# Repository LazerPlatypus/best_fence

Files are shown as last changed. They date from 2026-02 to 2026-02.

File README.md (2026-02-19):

# best_fence

3D-printable accessories for the Best Fence saw system.

## Overview

best_fence is an OpenSCAD design project that creates 3D-printable parts for working with the Best Fence woodworking measurement system.

**Features:**
- 3D-printable toe clamp system for securing the Best Fence to your workstation
- Modular mount design supporting 1–10 channels with configurable spacing
- Connectors for joining fence sections (butt connector) and mounting to saw horses

## Requirements

- **OpenSCAD** 2026.02.10 or newer
- **Python 3** (for documentation generation, optional)
- **openscad-docsgen** (installed via `make setup`)

## Quick Start

### 1. Preview
Open any file in `parts/` or `assemblies/` in OpenSCAD and press F5 to preview.

### 2. Build
```bash
make          # Build all STL files
```

### 3. Customize
Edit parameters in `config.scad` to adjust dimensions and settings.

## Building

```bash
# Build all parts
make

# Build specific part
make parts/butt_connector.scad build/stl/butt_connector.stl
make parts/saw_horse_connector.scad build/stl/saw_horse_connector.stl
make parts/toe_clamp_body.scad build/stl/toe_clamp_body.stl
make parts/toe_clamp_insert.scad build/stl/toe_clamp_insert.stl

# Generate documentation
make docs

# Render images
make images

# Clean build artifacts
make clean
```

## File Organization

- **[parts/](parts/)** - Printable 3D part source files
- **[assemblies/](assemblies/)** - Pre-configured assembly files for preview and export
- **[tools/](tools/)** - Reusable mount and attachment modules
- **[hardware/](hardware/)** - Hardware reference models (bolt, screw)
- **[scripts/](scripts/)** - Build automation scripts
- **[build/](build/)** - Generated STL files and images (run `make` to create)
- **[docs/](docs/)** - Documentation (hand-written + generated)
- **[config.scad](config.scad)** - Project-wide configuration

## Customization

All project settings can be adjusted in `config.scad`:
- Best Fence dimensions and tolerances
- Mount height and clearance
- Toe clamp geometry and sizing
- Hardware dimensions (bolt/screw)
- Rendering quality ($fn settings)

## Parts List

| Part | File | Description |
|---|---|---|
| Toe Clamp Body | `parts/toe_clamp_body.scad` | Main clamp body — print in TPU |
| Toe Clamp Insert | `parts/toe_clamp_insert.scad` | Stiffening insert for clamp — print in PLA/PETG |
| Butt Connector | `parts/butt_connector.scad` | Joins two fence sections end-to-end (2 channels) |
| Saw Horse Connector | `parts/saw_horse_connector.scad` | Mounts fence on a saw horse (1 channel) |

See [docs/bom.md](docs/bom.md) for complete bill of materials including hardware.

## Assembly

See [docs/assembly_instructions.md](docs/assembly_instructions.md) for step-by-step assembly instructions.

## Documentation

- **[API Reference](docs/api/)** - Generated API documentation
- **[Assembly Instructions](docs/assembly_instructions.md)** - How to assemble the parts
- **[Bill of Materials](docs/bom.md)** - Complete parts and hardware list

## Development

### Setup Development Environment
```bash
make setup
```

This creates a Python virtual environment and installs `openscad-docsgen` for documentation generation.

### Project Structure
```
best_fence/
├── README.md                        # Project overview
├── Makefile                         # Build automation
├── config.scad                      # Project configuration
├── .openscad_docsgen_rc             # Documentation config
├── parts/                           # Printable part source files
│   ├── toe_clamp_body.scad
│   ├── toe_clamp_insert.scad
│   ├── butt_connector.scad
│   └── saw_horse_connector.scad
├── assemblies/                      # Pre-configured assembly files
│   ├── butt_connector.scad
│   └── saw_horse_connector.scad
├── tools/                           # Reusable mount/attachment modules
│   ├── mount.scad
│   ├── attachment_helping_hand.scad
│   └── attachment_screw.scad
├── hardware/                        # Hardware reference models
│   ├── bolt.scad
│   └── screw.scad
├── scripts/                         # Build scripts
├── build/                           # Generated files (gitignored)
│   ├── stl/                        # STL exports
│   └── images/                     # Documentation renders
└── docs/                            # Documentation
    └── api/                        # Generated API docs
```

## Exporting with Variable Overrides

You can override variables from the command line:

```bash
# Export with custom bolt radius
./scripts/export_part.sh parts/toe_clamp_body.scad build/stl/toe_clamp_body.stl \
    "BOLT_HEAD_RADIUS=8"

# Export with lower resolution (faster)
./scripts/export_part.sh parts/toe_clamp_body.scad build/stl/toe_clamp_body_lowres.stl \
    "EXPORT_FN=16"
```

## Contributing

Contributions welcome! Please:
1. Follow the [OpenSCAD Style Guide](https://github.com/LazerPlatypus/openscad_guide/)
2. Document everything using [openscad_docsgen](https://github.com/BelfrySCAD/openscad_docsgen) format
3. Test your changes before submitting
4. Update documentation as needed

## Support

- **Issues:** [GitHub Issues](https://github.com/LazerPlatypus/best_fence/issues)
- **Documentation:** [docs/](docs/)

## License

This project is licensed under the **CERN Open Hardware License Version 2 – Strongly Reciprocal (CERN-OHL-S v2)**.

**Summary:**
- ✓ Use, modify, and manufacture (including commercially)
- ✓ Distribute original or modified versions
- ⚠️ Modified versions must use the same license
- ⚠️ Must provide complete source for any distributed modifications

See [LICENSE](LICENSE) for full license text.

---

**Status:** Active development
**Version:** 0.1.0 (pre-release)

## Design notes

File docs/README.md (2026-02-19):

# best_fence Documentation

This directory contains project documentation, including both hand-written guides and generated API documentation.

## Documentation Structure

### Hand-Written Documentation

- **[assembly_instructions.md](assembly_instructions.md)** - Step-by-step assembly guide
- **[bom.md](bom.md)** - Bill of materials (parts and hardware)

### Generated Documentation

- **[api/](api/)** - Auto-generated API documentation from source files
  - Generated by running `make docs`
  - Uses openscad_docsgen to extract documentation from code comments
  - Recreated each build, do not edit manually

## Updating Documentation

### To update hand-written docs:
1. Edit the scad files
2. run `make docs`
3. Commit changes to version control

### To regenerate API docs:
```bash
make docs
```

This will scan all documented functions and modules in:
- `assemblies/*.scad`
- `hardware/*.scad`
- `parts/*.scad`
- `tools/*.scad`

## Documentation Format

Use openscad_docsgen format for documenting functions and modules:

```scad
// Module: my_module
// Usage:
//   my_module(size);
// Description:
//   Creates a component with the specified size
// Arguments:
//   size = The size in millimeters
// Example(3D): Standard size
//   my_module(10);
module my_module(size) {
    cube([size, size, size]);
}
```

See: https://github.com/BelfrySCAD/openscad_docsgen

## Adding New Documentation

### For assembly steps:
Edit [assembly_instructions.md](assembly_instructions.md)

### For parts list:
Edit [bom.md](bom.md)

### For code documentation:
Add comments to your `.scad` files and run `make docs`

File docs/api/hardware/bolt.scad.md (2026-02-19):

# File: bolt.scad

A simple bolt component for holding the Best Fence, used by the [toe_clamp_body](parts/toe_clamp_body.scad)

To use, add the following lines to the beginning of your file:

    use <hardware/bolt.scad>;

## File Contents

- [`bolt`](#module-bolt)

### Module: bolt

**Usage:** 

- bolt();

**Description:** 

A simple bolt for holding the Best Fence, used by the [toe_clamp_body](parts/toe_clamp_body.scad)
This module creates a simple bolt with a hex head and no threads.

**Example 1:** 

``` {.C linenos=True}
use <hardware/bolt.scad>;
bolt();
```

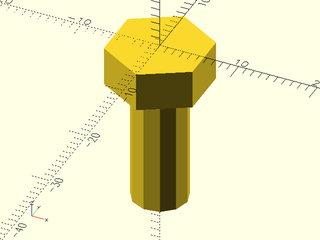
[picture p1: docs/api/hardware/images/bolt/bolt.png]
bolt Example 1


---

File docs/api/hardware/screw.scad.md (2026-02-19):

# File: screw.scad

To use, add the following lines to the beginning of your file:

    use <hardware/screw.scad>;

## File Contents

- [`screw`](#module-screw)

### Module: screw

**Usage:** 

- screw();

**Description:** 

A simple screw for holding the Best Fence, used by the [attachment_screw](tools/attachment_screw.scad)
This module creates a simple screw with a tapered head and no threads.

**Example 1:** 

``` {.C linenos=True}
use <hardware/screw.scad>;
screw();
```

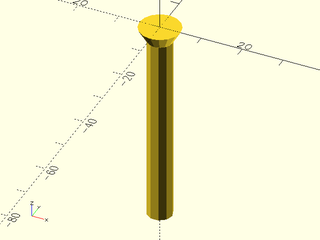
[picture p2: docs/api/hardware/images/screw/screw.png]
screw Example 1


---

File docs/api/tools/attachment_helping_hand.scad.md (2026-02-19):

# File: attachment\_helping\_hand.scad

To use, add the following lines to the beginning of your file:

    use <tools/attachment_helping_hand.scad>;

## File Contents

- [`attachment_helping_hand`](#module-attachment_helping_hand)

### Module: attachment\_helping\_hand

**Usage:** 

- attachment_helping_hand();

**Description:** 

A cylindar the same size as the head of the "Helping Hand"
should be used as the first child of the [mount](parts/mount.scad) module, with `mounting_face` set to "BOTTOM"
derives its dimensions from the variables in config.scad

**Example 1:** 

``` {.C linenos=True}
use <tools/attachment_helping_hand.scad>;
attachment_helping_hand();
```

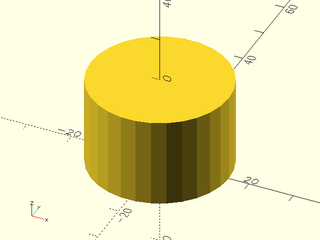
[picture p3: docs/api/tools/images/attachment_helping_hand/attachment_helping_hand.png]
attachment\_helping\_hand Example 1


---

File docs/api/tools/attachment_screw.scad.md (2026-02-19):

# File: attachment\_screw.scad

To use, add the following lines to the beginning of your file:

    use <tools/attachment_screw.scad>;

## File Contents

- [`attachment_screw`](#module-attachment_screw)

### Module: attachment\_screw

**Usage:** 

- attachment_screw();

**Description:** 

A simple screw mount for the Best Fence, used to attach the mount to the
saw stand. This module creates a 2x2 group of screws using variables in config.scad
This should be the first child of the [mount](parts/mount.scad) module with `mounting_face` set to "TOP"

**Example 1:** 

``` {.C linenos=True}
use <tools/attachment_screw.scad>;
attachment_screw();
```

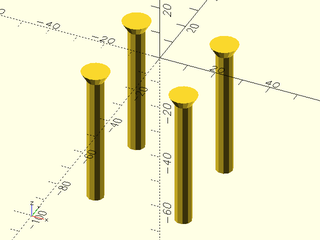
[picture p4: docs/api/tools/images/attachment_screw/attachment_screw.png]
attachment\_screw Example 1


---

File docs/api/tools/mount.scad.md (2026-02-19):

# File: mount.scad

This part interfaces with the BestFence system
It has slots for channels and a blind hole for a "helping hand" arm

To use, add the following lines to the beginning of your file:

    use <tools/mount.scad>;

## File Contents

- [`mount`](#module-mount)
- [`_validate_args_mount()`](#function-_validate_args_mount)
- [`_calculate_support_points()`](#function-_calculate_support_points)
- [`_calculate_channel_points()`](#function-_calculate_channel_points)

### Module: mount

**Usage:** 

- mount(num_channels=2, channel_spacing=20);

**Usage:** 

- mount(num_channels=2, channel_spacing=20) { <attachment_geometry>; <channel_geometry> }

**Description:** 

Creates a mount for the BestFence system with specified number of channels and spacing.

uses global variables in config.scad to create the correct toe clamp, helping hand hole, and attachment geometry.

use children to add additional geometry to the mount. first child should be the attachment mechanism, the second child will
be duplicated in each `channel` slot.

**Arguments:** 

<abbr title="These args can be used by position or by name.">By&nbsp;Position</abbr> | What it does
-------------------- | ------------
`num_channels`       | `number` Number of channels to include in the mount (default: 2)
`channel_spacing`    | `number` Spacing between channels in mm (default: 20)
`mounting_face`      | `string` Which face to mount the channels on. Allowed values: "TOP", "BOTTOM" (default: "BOTTOM")

**Example 1:** One Channel, top mount

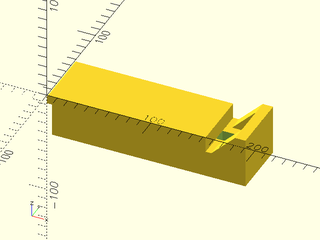
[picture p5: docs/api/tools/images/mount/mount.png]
mount Example 1


``` {.C linenos=True}
use <tools/mount.scad>;
mount(num_channels=1, channel_spacing=14, mounting_face="TOP");
```

**Example 2:** Two Channels, bottom mount

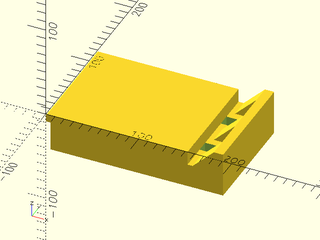
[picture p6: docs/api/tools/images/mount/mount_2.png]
mount Example 2


``` {.C linenos=True}
use <tools/mount.scad>;
mount(num_channels=2, channel_spacing=20, mounting_face="BOTTOM");
```

---

### Function: \_validate\_args\_mount()

**Status:** INTERNAL

**Description:** 

Validates the arguments passed to mount() and throws an error if any are invalid

**Arguments:** 

<abbr title="These args can be used by position or by name.">By&nbsp;Position</abbr> | What it does
-------------------- | ------------
`num_channels`       | `number` Number of channels to include in the mount (must be greater than 1, less than 11)
`channel_spacing`    | `number` Spacing between channels in mm (must be greater than 0)
`mounting_face`      | `string` Which face to mount the channels on. Allowed values: "TOP", "BOTTOM"

**Example 1:** Valid arguments

``` {.C linenos=True}
use <tools/mount.scad>;
// valid
_validate_args_mount(2, 20, "BOTTOM");
```

**Example 2:** Invalid `num_channels`

``` {.C linenos=True}
use <tools/mount.scad>;
_validate_args_mount(0, 20, "BOTTOM");
// throws error "Invalid num_channels value. Must be between 1 and 10."
```

**Example 3:** Invalid `channel_spacing`

``` {.C linenos=True}
use <tools/mount.scad>;
_validate_args_mount(2, -5, "BOTTOM");
// throws error "Invalid channel_spacing value. Must be greater than 0."
```

**Example 4:** Invalid `mounting_face`

``` {.C linenos=True}
use <tools/mount.scad>;
_validate_args_mount(2, 20, "SIDE");
// throws error "Invalid mounting_face value. Allowed values: 'TOP', 'BOTTOM'."
```

---

### Function: \_calculate\_support\_points()

**Status:** INTERNAL

**Description:** 

Calculates the points for the support geometry based on global variables

**Example 1:** 

``` {.C linenos=True}
use <tools/mount.scad>;
use <deps/coord_kit/core.scad>;
polygon(points_to_coords(_calculate_support_points()));
```

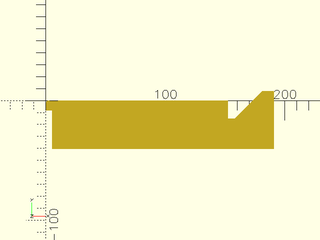
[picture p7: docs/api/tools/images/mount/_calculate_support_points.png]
\_calculate\_support\_points() Example 1


---

### Function: \_calculate\_channel\_points()

**Status:** INTERNAL

**Description:** 

Calculates the points for the channel geometry based on global variables

**Example 1:** 

``` {.C linenos=True}
use <tools/mount.scad>;
use <deps/coord_kit/core.scad>;
polygon(points_to_coords(_calculate_channel_points()));
```

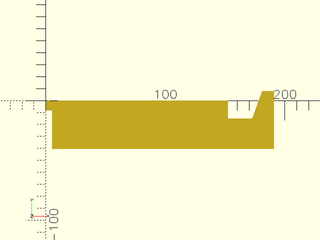
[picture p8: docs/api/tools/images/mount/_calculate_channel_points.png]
\_calculate\_channel\_points() Example 1


---

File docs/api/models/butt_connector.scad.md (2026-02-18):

# File: butt\_connector.scad

A simple connector for attaching two pieces of Best Fence together

To use, add the following lines to the beginning of your file:

    include <models/butt_connector.scad>;

## File Contents

- [`butt_connector`](#module-butt_connector)

### Module: butt\_connector

**Description:** 

A simple connector for attaching two pieces of Best Fence together

**Example 1:** Exported Geometry

``` {.C linenos=True}
include <models/butt_connector.scad>;
butt_connector();
```

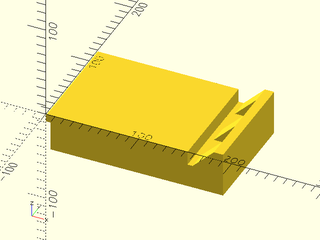
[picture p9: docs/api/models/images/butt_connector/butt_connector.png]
butt\_connector Example 1


**Example 2:** Full Assembly

``` {.C linenos=True}
include <models/butt_connector.scad>;
butt_connector() {
    union() {
        rotate([0, 0, 180]) {
            color("blue") {
                toe_clamp_body(){
                    translate([0, 0, EPSILON]) {
                        bolt();
                        toe_clamp_insert() {
                            translate([0, 0, EPSILON]) {
                                bolt();
                            }
                        }
                    }
                }
            }
            color("white") {
                toe_clamp_insert() {
                    translate([0, 0, EPSILON]) {
                        bolt();
                    }
                }
            }
            color("black") {
                bolt();
            }
        }
    }
}
```

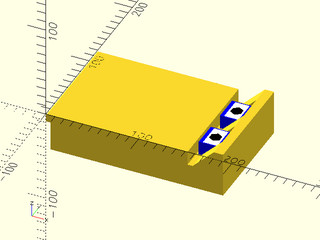
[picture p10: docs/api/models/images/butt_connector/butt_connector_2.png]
butt\_connector Example 2


---

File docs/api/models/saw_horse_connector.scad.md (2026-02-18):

# File: saw\_horse\_connector.scad

A simple connector for attaching the Best Fence to a saw horse

To use, add the following lines to the beginning of your file:

    include <models/saw_horse_connector.scad>;

## File Contents

- [`saw_horse_connector`](#module-saw_horse_connector)

### Module: saw\_horse\_connector

**Description:** 

A simple connector for attaching the Best Fence to a saw horse

**Example 1:** Exported Geometry

``` {.C linenos=True}
include <models/saw_horse_connector.scad>;
saw_horse_connector();
```

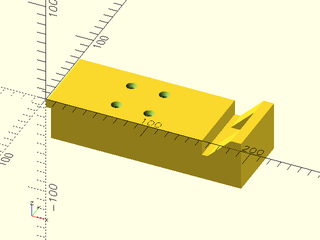
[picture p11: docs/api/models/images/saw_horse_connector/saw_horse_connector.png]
saw\_horse\_connector Example 1


**Example 2:** Full Assembly

``` {.C linenos=True}
include <models/saw_horse_connector.scad>;
saw_horse_connector() {
    union() {
        rotate([0, 0, 180]) {
            color("blue") {
                toe_clamp_body(){
                    translate([0, 0, EPSILON]) {
                        bolt();
                        toe_clamp_insert() {
                            translate([0, 0, EPSILON]) {
                                bolt();
                            }
                        }
                    }
                }
            }
            color("white") {
                toe_clamp_insert() {
                    translate([0, 0, EPSILON]) {
                        bolt();
                    }
                }
            }
            color("black") {
                bolt();
            }
        }
    }
}
```

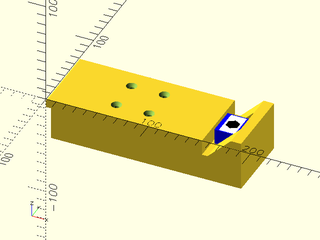
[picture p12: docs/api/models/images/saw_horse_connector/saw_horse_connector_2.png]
saw\_horse\_connector Example 2


---

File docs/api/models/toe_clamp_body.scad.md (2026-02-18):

# File: toe\_clamp\_body.scad

A simple toe clamp component for holding the Best Fence

To use, add the following lines to the beginning of your file:

    include <models/toe_clamp_body.scad>;

## File Contents

- [`toe_clamp_body`](#module-toe_clamp_body)
- [`_calculate_toe_clamp_body_points`](#function-_calculate_toe_clamp_body_points)
- [`_calculate_center_x_toe_clamp_body`](#function-_calculate_center_x_toe_clamp_body)

### Module: toe\_clamp\_body

**Description:** 

A simple toe clamp for holding the Best Fence
This module creates a simple toe clamp body that takes the [toe_clamp_insert](models/toe_clamp_insert.scad) and a bolt as children
This module is centered around 0,0,0, meaning all children should be centered about 0,0,0 as well.
to secure the clamp to the fence. The clamp body is designed to fit snugly around the insert and provide a secure hold on the fence.
it is recommended to make the body from a rubbery/grippy material like TPU

**Example 1:** 

``` {.C linenos=True}
include <models/toe_clamp_body.scad>;
toe_clamp_body() {
  translate([0, 0, EPSILON]) {
    bolt();
    toe_clamp_insert() {
     translate([0, 0, EPSILON]) {
        bolt();
      }
    }
  }
}
```

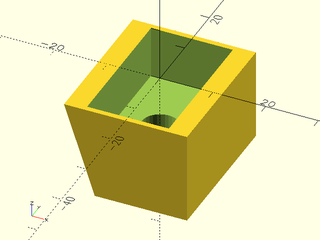
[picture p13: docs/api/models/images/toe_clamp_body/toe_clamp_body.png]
toe\_clamp\_body Example 1


---

### Function: \_calculate\_toe\_clamp\_body\_points

**Status:** INTERNAL

**Description:** 

Calculates the points for the toe clamp body geometry based on global variables

**Example 1:** 

``` {.C linenos=True}
include <models/toe_clamp_body.scad>;
polygon(points_to_coords(_calculate_toe_clamp_body_points()));
```

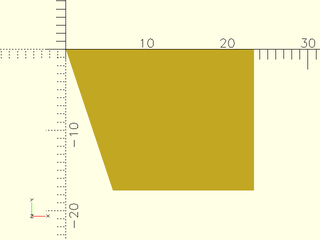
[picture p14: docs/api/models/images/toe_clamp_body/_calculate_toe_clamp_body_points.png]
\_calculate\_toe\_clamp\_body\_points Example 1


---

### Function: \_calculate\_center\_x\_toe\_clamp\_body

**Status:** INTERNAL

**Description:** 

Calculates the center x coordinate for the toe clamp body geometry based on the points

**Example 1:** 

``` {.C linenos=True}
include <models/toe_clamp_body.scad>;
_calculate_center_x_toe_clamp_body(_calculate_toe_clamp_body_points());
```

---

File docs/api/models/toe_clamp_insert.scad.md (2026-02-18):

# File: toe\_clamp\_insert.scad

A simple toe clamp component for holding the Best Fence

To use, add the following lines to the beginning of your file:

    include <models/toe_clamp_insert.scad>;

## File Contents

- [`toe_clamp_insert`](#module-toe_clamp_insert)

### Module: toe\_clamp\_insert

**Description:** 

A simple toe clamp insert for holding the Best Fence, used by the [toe_clamp_body](models/toe_clamp_body.scad)
This module creates a simple toe clamp insert that is designed to fit snugly inside the [toe_clamp_body](models/toe_clamp_body.scad)
and provide a secure hold on the fence. The insert is designed to be used with a bolt that goes through the [toe_clamp_body](models/toe_clamp_body.scad)
and secures the clamp to the fence.

The insert is designed to be centered around 0,0, with the highest point at 0,0,0;

**Example 1:** 

``` {.C linenos=True}
include <models/toe_clamp_insert.scad>;
toe_clamp_insert() {
  translate([0, 0, EPSILON]) {
    bolt();
  }
}
```

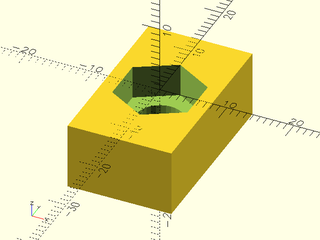
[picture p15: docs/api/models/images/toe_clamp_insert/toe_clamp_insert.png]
toe\_clamp\_insert Example 1


---

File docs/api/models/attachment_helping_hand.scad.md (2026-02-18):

# File: attachment\_helping\_hand.scad

To use, add the following lines to the beginning of your file:

    include <models/attachment_helping_hand.scad>;

## File Contents

- [`attachment_helping_hand`](#module-attachment_helping_hand)

### Module: attachment\_helping\_hand

**Description:** 

A cylindar the same size as the head of the "Helping Hand"
should be used as the first child of the [mount](models/mount.scad#module-mount) module, with `mounting_face` set to "BOTTOM"
derives its dimensions from the variables in config.scad

**Example 1:** 

``` {.C linenos=True}
include <models/attachment_helping_hand.scad>;
attachment_helping_hand();
```

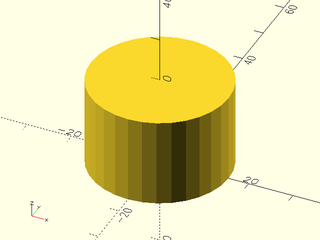
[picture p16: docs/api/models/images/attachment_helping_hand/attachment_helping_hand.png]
attachment\_helping\_hand Example 1


---

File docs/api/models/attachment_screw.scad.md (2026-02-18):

# File: attachment\_screw.scad

To use, add the following lines to the beginning of your file:

    include <models/attachment_screw.scad>;

## File Contents

- [`attachment_screw`](#module-attachment_screw)
- [`screw`](#module-screw)

### Module: attachment\_screw

**Description:** 

A simple screw mount for the Best Fence, used to attach the mount to the
saw stand. This module creates a 2x2 group of screws using variables in config.scad
This should be the first child of the [mount](models/mount.scad#module-mount) module with `mounting_face` set to "TOP"

**Example 1:** 

``` {.C linenos=True}
include <models/attachment_screw.scad>;
attachment_screw();
```

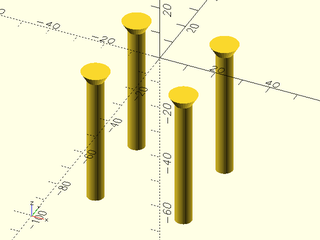
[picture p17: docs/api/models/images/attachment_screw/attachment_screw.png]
attachment\_screw Example 1


---

### Module: screw

**Description:** 

A simple screw for holding the Best Fence, used by the [attachment\_screw](#module-attachment_screw)
This module creates a simple screw with a tapered head and no threads.

**Example 1:** 

``` {.C linenos=True}
include <models/attachment_screw.scad>;
screw();
```

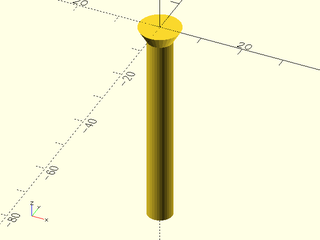
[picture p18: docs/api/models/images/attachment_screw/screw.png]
screw Example 1


---

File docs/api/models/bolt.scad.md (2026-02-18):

# File: bolt.scad

A simple bolt component for holding the Best Fence, used by the [toe\_clamp\_body](models/toe_clamp_body.scad#module-toe_clamp_body)

To use, add the following lines to the beginning of your file:

    include <models/bolt.scad>;

## File Contents

- [`bolt`](#module-bolt)

### Module: bolt

**Description:** 

A simple bolt for holding the Best Fence, used by the [toe\_clamp\_body](models/toe_clamp_body.scad#module-toe_clamp_body)
This module creates a simple bolt with a hex head and no threads.

**Example 1:** 

``` {.C linenos=True}
include <models/bolt.scad>;
bolt();
```

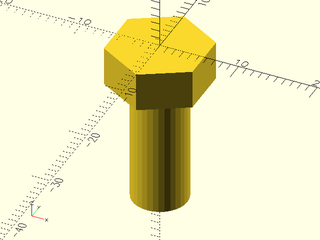
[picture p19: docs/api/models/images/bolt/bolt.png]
bolt Example 1


---

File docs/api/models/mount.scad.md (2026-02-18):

# File: mount.scad

This part interfaces with the BestFence system
It has slots for channels and a blind hole for a "helping hand" arm

To use, add the following lines to the beginning of your file:

    include <models/mount.scad>;

## File Contents

- [`mount`](#module-mount)
- [`_validate_args_mount()`](#function-_validate_args_mount)
- [`_calculate_support_points()`](#function-_calculate_support_points)
- [`_calculate_channel_points()`](#function-_calculate_channel_points)

### Module: mount

**Usage:** 

- mount(num_channels=2, channel_spacing=20);

**Description:** 

Creates a mount for the BestFence system with specified number of channels and spacing.

uses global variables in config.scad to create the correct toe clamp, helping hand hole, and attachment geometry.

use children to add additional geometry to the mount. first child should be the attachment mechanism, the second child will
be duplicated in each `channel` slot.

**Arguments:** 

<abbr title="These args can be used by position or by name.">By&nbsp;Position</abbr> | What it does
-------------------- | ------------
`num_channels`       | `number` Number of channels to include in the mount (default: 2)
`channel_spacing`    | `number` Spacing between channels in mm (default: 20)
`mounting_face`      | `string` Which face to mount the channels on. Allowed values: "TOP", "BOTTOM" (default: "BOTTOM")

**Example 1:** One Channel, top mount

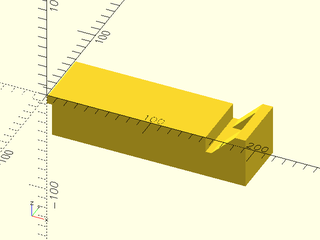
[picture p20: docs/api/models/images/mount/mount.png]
mount Example 1


``` {.C linenos=True}
include <models/mount.scad>;
mount(num_channels=1, channel_spacing=14, mounting_face="TOP");
```

**Example 2:** Two Channels, bottom mount

mount Example 2

``` {.C linenos=True}
include <models/mount.scad>;
mount(num_channels=2, channel_spacing=20, mounting_face="BOTTOM");
```

---

### Function: \_validate\_args\_mount()

**Status:** INTERNAL

**Description:** 

Validates the arguments passed to mount() and throws an error if any are invalid

**Arguments:** 

<abbr title="These args can be used by position or by name.">By&nbsp;Position</abbr> | What it does
-------------------- | ------------
`num_channels`       | `number` Number of channels to include in the mount (must be greater than 1, less than 11)
`channel_spacing`    | `number` Spacing between channels in mm (must be greater than 0)
`mounting_face`      | `string` Which face to mount the channels on. Allowed values: "TOP", "BOTTOM"

**Example 1:** Valid arguments

``` {.C linenos=True}
include <models/mount.scad>;
// valid
_validate_args_mount(2, 20, "BOTTOM");
```

**Example 2:** Invalid `num_channels`

``` {.C linenos=True}
include <models/mount.scad>;
_validate_args_mount(0, 20, "BOTTOM");
// throws error "Invalid num_channels value. Must be between 1 and 10."
```

**Example 3:** Invalid `channel_spacing`

``` {.C linenos=True}
include <models/mount.scad>;
_validate_args_mount(2, -5, "BOTTOM");
// throws error "Invalid channel_spacing value. Must be greater than 0."
```

**Example 4:** Invalid `mounting_face`

``` {.C linenos=True}
include <models/mount.scad>;
_validate_args_mount(2, 20, "SIDE");
// throws error "Invalid mounting_face value. Allowed values: 'TOP', 'BOTTOM'."
```

---

### Function: \_calculate\_support\_points()

**Status:** INTERNAL

**Description:** 

Calculates the points for the support geometry based on global variables

**Example 1:** 

``` {.C linenos=True}
include <models/mount.scad>;
polygon(points_to_coords(_calculate_support_points()));
```

\_calculate\_support\_points() Example 1

---

### Function: \_calculate\_channel\_points()

**Status:** INTERNAL

**Description:** 

Calculates the points for the channel geometry based on global variables

**Example 1:** 

``` {.C linenos=True}
include <models/mount.scad>;
polygon(points_to_coords(_calculate_channel_points()));
```

\_calculate\_channel\_points() Example 1

---

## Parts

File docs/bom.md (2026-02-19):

# Bill of Materials

This document lists all parts needed to build one complete best_fence setup. Quantities depend on your configuration — see the notes per section.

---

## 3D Printed Parts

Print these from the STL files in `build/stl/` (run `make` to generate).

| Part | File | Material | Qty (per use) | Notes |
|---|---|---|---|---|
| Toe Clamp Body | `toe_clamp_body.stl` | TPU | 1 per channel | Flexible/grippy — one per toe clamp station |
| Toe Clamp Insert | `toe_clamp_insert.stl` | PLA | 1 per channel | Rigid insert — one per toe clamp station |
| Butt Connector | `butt_connector.stl` | PLA | 1 per fence joint | Has 2 channels; needs 2 toe clamp sets |
| Saw Horse Connector | `saw_horse_connector.stl` | PLA | 1 per saw horse | Has 1 channel; needs 1 toe clamp set |

**Example:** A setup with 2 saw horses and 1 butt-joined fence section would need:
- 2x Saw Horse Connector (2 channels total → 2 toe clamp sets)
- 1x Butt Connector (2 channels → 2 toe clamp sets)
- **4x** Toe Clamp Body, **4x** Toe Clamp Insert

---

## Hardware

### Toe Clamp Hardware

The following hardware is required per toe clamp channel. The stack from top to bottom is:
**bolt head → toe clamp insert → toe clamp body → nut → spring → connector body → washer → knob**

| Item | Spec | Notes |
|---|---|---|
| Hex bolt | **1/4"-20 × 2"** | McMaster-Carr [#92865A549](https://www.mcmaster.com/catalog/132/3578/92865A549) — avoid cheap hardware store bolts, they can strip in the brass knob |
| Hex nut | 1/4"-20, zinc | McMaster-Carr [#95462A029](https://www.mcmaster.com/products/95462a029/) |
| Spring | **3/4" long, 3/8" OD**, spring rate ~8.9 lb/in | McMaster-Carr [#9657K289](https://www.mcmaster.com/products/9657k289/) — the spring is critical; exact spring rate matters less than the dimensions |
| Washer | 1/4", zinc (optional) | McMaster-Carr [#92141A029](https://www.mcmaster.com/products/92141a029/) — between connector body and knob |
| Knob | 1/4"-20 plastic knob with brass threaded insert | Hardware store knob works; McMaster-Carr [#6185K21](https://www.mcmaster.com/6185K21/) if ordering online |

### Saw Horse Mounting Screws

Four screws are required per saw horse connector. The connector mounts to a **wood block** (not directly to the saw horse), which lets you dial in the exact height.

| Item | Spec | Notes |
|---|---|---|
| Wood screw | **#10** | Length depends on your wood block thickness |
| Wood block | User-provided | Sized and mounted to the saw horse to set the fence height |
| Pattern | 2×2 grid, 32mm spacing | Matches `SCREW_MOUNT_WIDTH/LENGTH = 32mm` in `config.scad` |
| Qty per connector | 4 | |

### FastCap 3rd Hand

One [FastCap 3rd Hand](https://www.fastcap.com/products/3rd-hand-series) arm is required per butt connector. It clips onto the bottom of the Best Fence rail and the arm slides into the cylindrical pocket on the underside of the connector to support it from below.

| Attribute | Value |
|---|---|
| Product | FastCap 3rd Hand |
| Source | [fastcap.com](https://www.fastcap.com/products/3rd-hand-series) |
| Qty per butt connector | 1 |

---

## Summary Table (per typical 2-saw-horse setup)

| Item | Qty |
|---|-----|
| Toe Clamp Body (TPU) | 4 |
| Toe Clamp Insert (PLA) | 4 |
| Butt Connector (PLA) | 1 |
| Saw Horse Connector (PLA) | 2 |
| 1/4"-20 × 2" hex bolt (McMaster [#92865A549](https://www.mcmaster.com/catalog/132/3578/92865A549)) | 4 |
| 1/4"-20 hex nut, zinc (McMaster [#95462A029](https://www.mcmaster.com/products/95462a029/)) | 4 |
| Spring 3/4" × 3/8" OD (McMaster [#9657K289](https://www.mcmaster.com/products/9657k289/)) | 4 |
| 1/4" washer, zinc, optional (McMaster [#92141A029](https://www.mcmaster.com/products/92141a029/)) | 4 |
| 1/4"-20 plastic knob w/ brass insert (McMaster [#6185K21](https://www.mcmaster.com/6185K21/)) | 4 |
| #10 wood screws | 8 |
| Wood mounting blocks | 2 |
| FastCap 3rd Hand | 1 |

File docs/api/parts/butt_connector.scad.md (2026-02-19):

# File: butt\_connector.scad

A simple connector for attaching two pieces of Best Fence together

To use, add the following lines to the beginning of your file:

    use <parts/butt_connector.scad>;

## File Contents

- [`butt_connector`](#module-butt_connector)

### Module: butt\_connector

**Usage:** 

- butt_connector(){ <toe_clamp (optional)>; }

**Description:** 

A simple connector for attaching two pieces of Best Fence together

**Example 1:** Exported Geometry

``` {.C linenos=True}
use <parts/butt_connector.scad>;
butt_connector();
```

butt\_connector Example 1

---

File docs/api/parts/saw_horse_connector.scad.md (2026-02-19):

# File: saw\_horse\_connector.scad

A simple connector for attaching the Best Fence to a saw horse

To use, add the following lines to the beginning of your file:

    use <parts/saw_horse_connector.scad>;

## File Contents

- [`saw_horse_connector`](#module-saw_horse_connector)

### Module: saw\_horse\_connector

**Usage:** 

- saw_horse_connector() { <toe_clamp (optional)>; }

**Description:** 

A simple connector for attaching the Best Fence to a saw horse

**Example 1:** Exported Geometry

``` {.C linenos=True}
use <parts/saw_horse_connector.scad>;
saw_horse_connector();
```

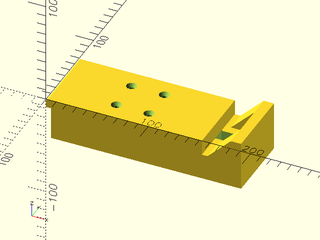
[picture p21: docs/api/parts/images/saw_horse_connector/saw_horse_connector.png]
saw\_horse\_connector Example 1


---

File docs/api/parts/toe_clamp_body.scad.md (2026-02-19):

# File: toe\_clamp\_body.scad

A simple toe clamp component for holding the Best Fence

To use, add the following lines to the beginning of your file:

    use <parts/toe_clamp_body.scad>;

## File Contents

- [`toe_clamp_body`](#module-toe_clamp_body)
- [`_calculate_toe_clamp_body_points`](#function-_calculate_toe_clamp_body_points)
- [`_calculate_center_x_toe_clamp_body`](#function-_calculate_center_x_toe_clamp_body)

### Module: toe\_clamp\_body

**Usage:** 

- toe_clamp_body() { <toe_clamp_insert (optional)>; }

**Description:** 

A simple toe clamp for holding the Best Fence
This module creates a simple toe clamp body that takes the [toe_clamp_insert](parts/toe_clamp_insert.scad) and a bolt as children
This module is centered around 0,0,0, meaning all children should be centered about 0,0,0 as well.
to secure the clamp to the fence. The clamp body is designed to fit snugly around the insert and provide a secure hold on the fence.
it is recommended to make the body from a rubbery/grippy material like TPU

**Example 1:** 

``` {.C linenos=True}
use <parts/toe_clamp_body.scad>;
use <parts/toe_clamp_insert.scad>;
use <hardware/bolt.scad>;
include <config.scad>;
toe_clamp_body() {
  translate([0, 0, EPSILON]) {
    bolt();
    toe_clamp_insert() {
     translate([0, 0, EPSILON]) {
        bolt();
      }
    }
  }
}
```

toe\_clamp\_body Example 1

---

### Function: \_calculate\_toe\_clamp\_body\_points

**Status:** INTERNAL

**Description:** 

Calculates the points for the toe clamp body geometry based on global variables

**Example 1:** 

``` {.C linenos=True}
use <parts/toe_clamp_body.scad>;
use <deps/coord_kit/core.scad>;
polygon(points_to_coords(_calculate_toe_clamp_body_points()));
```

\_calculate\_toe\_clamp\_body\_points Example 1

---

### Function: \_calculate\_center\_x\_toe\_clamp\_body

**Status:** INTERNAL

**Description:** 

Calculates the center x coordinate for the toe clamp body geometry based on the points

**Example 1:** 

``` {.C linenos=True}
use <parts/toe_clamp_body.scad>;
_calculate_center_x_toe_clamp_body(_calculate_toe_clamp_body_points());
```

---

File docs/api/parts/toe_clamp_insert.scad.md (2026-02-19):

# File: toe\_clamp\_insert.scad

A simple toe clamp component for holding the Best Fence

To use, add the following lines to the beginning of your file:

    use <parts/toe_clamp_insert.scad>;

## File Contents

- [`toe_clamp_insert`](#module-toe_clamp_insert)

### Module: toe\_clamp\_insert

**Usage:** 

- toe_clamp_insert() { <bolt>; }

**Description:** 

A simple toe clamp insert for holding the Best Fence, used by the [toe_clamp_body](parts/toe_clamp_body.scad)
This module creates a simple toe clamp insert that is designed to fit snugly inside the [toe_clamp_body](parts/toe_clamp_body.scad)
and provide a secure hold on the fence. The insert is designed to be used with a bolt that goes through the [toe_clamp_body](parts/toe_clamp_body.scad)
and secures the clamp to the fence.

The insert is designed to be centered around 0,0, with the highest point at 0,0,0;

**Example 1:** 

``` {.C linenos=True}
use <parts/toe_clamp_insert.scad>;
use <hardware/bolt.scad>;
include <config.scad>;
toe_clamp_insert() {
  translate([0, 0, EPSILON]) {
    bolt();
  }
}
```

toe\_clamp\_insert Example 1

---

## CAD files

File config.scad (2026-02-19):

// ============================================================
// PROJECT CONFIGURATION
// Description: Global settings for best_fence
// ============================================================

// ============================================================
// RENDERING SETTINGS
// ============================================================

// Preview quality (lower = faster preview)
PREVIEW_FN = 32;

// Export quality (higher = smoother STL)
EXPORT_FN = 128;

// Current mode (set to true when exporting STL)
// Override from command line: openscad -D 'EXPORT_MODE=true' ...
EXPORT_MODE = false;

// Convenience variable - automatically use correct quality
$fn = EXPORT_MODE ? EXPORT_FN : PREVIEW_FN;

// ============================================================
// PROJECT DIMENSIONS (mm and degrees)
// ============================================================

// best fence dimensions
// TODO: create a model of the best fence for reference
BEST_FENCE_INTERIOR_WIDTH = 152.5;
BEST_FENCE_INTERIOR_HEIGHT = 15;
BEST_FENCE_OVERALL_HEIGHT = 25;
BEST_FENCE_WALL_THICKNESS = 5.5;
BEST_FENCE_INDEXING_LIP_LENGTH = 5;
BEST_FENCE_INDEXING_LIP_HEIGHT = 8.5;

// mount dimensions
MOUNT_HEIGHT = 32;
// MOUNT_VERTICAL_CLEARANCE is the vertical clearance between the highest point of 
// the mount and the top of the Best Fence. 
// Negative values means it will be below the top of the Best Fence.
MOUNT_VERTICAL_CLEARANCE = -2; 
MOUNT_REAR_SUPPORT_WIDTH = 10;

// toe clamp dimensions
TOE_CLAMP_LENGTH = 28;
TOE_CLAMP_BOTTOM_WIDTH = 17.5;
TOE_CLAMP_ANGLE = 70; 
TOE_CLAMP_HEIGHT = 16;
TOE_CLAMP_INSERT_WIDTH = TOE_CLAMP_BOTTOM_WIDTH - 2; // should be slightly smaller than the bottom width of the clamp body to fit snugly
TOE_CLAMP_INSERT_LENGTH = TOE_CLAMP_LENGTH - 2; // should be slightly smaller than the length of the clamp body to fit snugly
TOE_CLAMP_INSERT_HEIGHT = 10;

// bolt dimensions
BOLT_HEAD_RADIUS = 6.5;
BOLT_HEAD_HEIGHT = 5;
BOLT_SHANK_RADIUS = 3.5;
BOLT_SHANK_HEIGHT = 16;

// spring dimensions
SPRING_RADIUS = 6.5;
SPRING_HEIGHT = 13;

// screw mount dimensions
SCREW_MOUNT_WIDTH = 32;
SCREW_MOUNT_LENGTH = 32;

// screw dimensions
SCREW_HEAD_RADIUS = 5;
SCREW_SHANK_RADIUS = 3;
SCREW_HEAD_ANGLE = 30; 
SCREW_HEIGHT = 50;

// helping hand dimensions
HELPING_HAND_HEAD_HEIGHT = 20;
HELPING_HAND_HEAD_RADIUS = 15.5;

// ============================================================
// TOLERANCES (mm and degrees)
// ============================================================

TOE_CLAMP_TOLERANCE_LENGTH = 1;
TOE_CLAMP_TOLERANCE_WIDTH = -3;

EPSILON = 1e-3;

// ============================================================
// RENDERING HELPERS
// ============================================================

// Helper function to determine if we're in preview mode
function is_preview() = !EXPORT_MODE;

// Helper function to determine if we're in export mode
function is_export() = EXPORT_MODE;

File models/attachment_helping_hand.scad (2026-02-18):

// File: attachment_helping_hand.scad
// A model of the top of the "Helping Hand" attachment for the Best Fence,
// which holds the mount from the bottom
// Includes:
//   include <models/attachment_helping_hand.scad>;

include <../config.scad>;

// Module: attachment_helping_hand
// Description: A cylindar the same size as the head of the "Helping Hand"
//   should be used as the first child of the {{mount}} module, with `mounting_face` set to "BOTTOM"
//   derives its dimensions from the variables in config.scad
// Example(3D):
//   attachment_helping_hand();
module attachment_helping_hand() {
    cylinder(
        h = HELPING_HAND_HEAD_HEIGHT, 
        r = HELPING_HAND_HEAD_RADIUS, 
        center = false,
    );
}

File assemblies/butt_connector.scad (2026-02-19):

// File: butt_connector.scad
//   This file defines the assembly for the butt connector, which includes the toe clamp body, toe clamp insert, and bolts. 
//   It uses the parts defined in parts/butt_connector.scad.
// Includes: 
//   include <assemblies/butt_connector.scad>;

include <../parts/butt_connector.scad>;
include <../config.scad>;

// Module: butt_connector_assembly
// Description: This module assembles the butt connector by combining the toe clamp body, toe clamp insert, and bolts in the correct orientation and position.
// Usage:
//   butt_connector_assembly();
// Example(3D,Render):
//   -- EXPORT_MODE = false;
//   butt_connector_assembly();
module butt_connector_assembly() {
    butt_connector() {
        union() {
            rotate([0, 0, 180]) {
                color("blue") {
                    toe_clamp_body(){
                        translate([0, 0, EPSILON]) {
                            bolt();
                            toe_clamp_insert() {
                                translate([0, 0, EPSILON]) {
                                    bolt();
                                }
                            }
                        }
                    }
                }
                color("white") {
                    toe_clamp_insert() {
                        translate([0, 0, EPSILON]) {
                            bolt();
                        }
                    }
                }
                color("black") {
                    bolt();
                }
            }
        }
    }
}

if (EXPORT_MODE) {
    butt_connector_assembly();
}

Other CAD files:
assemblies/saw_horse_connector.scad
hardware/bolt.scad
hardware/screw.scad
models/attachment_screw.scad
models/bolt.scad
models/butt_connector.scad
models/mount.scad
models/saw_horse_connector.scad
models/toe_clamp_body.scad
models/toe_clamp_insert.scad
parts/butt_connector.scad
parts/saw_horse_connector.scad
parts/toe_clamp_body.scad
parts/toe_clamp_insert.scad
tools/attachment_helping_hand.scad
tools/attachment_screw.scad
tools/mount.scad

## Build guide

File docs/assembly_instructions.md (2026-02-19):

# Assembly Instructions

This document covers how to print and assemble each component in the best_fence system.

See [bom.md](bom.md) for the full parts and hardware list.

---

## Printing Guidelines

### Material Recommendations

| Part | Material | Notes |
|---|---|---|
| `toe_clamp_body` | **TPU** | Flexible/grippy material gives a secure hold on the fence |
| `toe_clamp_insert` | **PLA** | Rigid insert provides structural support inside the clamp body |
| `butt_connector` | **PLA** | Structural part — rigidity preferred (see Print Settings below) |
| `saw_horse_connector` | **PLA** | Structural part — rigidity preferred (see Print Settings below) |

### Print Settings

#### Connectors and Inserts (PLA recommended)

**PLA Basic (e.g. Bambu Labs PLA Basic)** works surprisingly well and is the recommended choice:
- **6 top/bottom layers, 4 walls, 25% infill**
- PLA's combination of rigidity and impact resistance at this wall thickness is ideal
- Heat warping is a theoretical concern for outdoor summer use (110°F+ days), but has not been a practical problem in testing

**Alternative: PC CF GF** (e.g. [Priline Superhard CF PC](https://a.co/d/026GdiBA)) is the only other material that has worked well in practice. Standard PC, PA, PA-CF, and PETG have all been tested and found to be unsuitable.

#### Toe Clamp Body (TPU)

> **Note:** Specific TPU print settings not yet documented.

---

## Toe Clamp Assembly

The toe clamp is a two-part clamping system that grips the outside of the Best Fence rail. Each mount channel requires one complete toe clamp assembly (body + insert + bolt).

### Parts needed (per channel)
- 1x `toe_clamp_body` (TPU)
- 1x `toe_clamp_insert` (PLA)
- 1x 1/4"-20 × 2" hex bolt (McMaster-Carr [#92865A549](https://www.mcmaster.com/catalog/132/3578/92865A549))
- 1x 1/4"-20 hex nut, zinc (McMaster-Carr [#95462A029](https://www.mcmaster.com/products/95462a029/))
- 1x spring, 3/4" long × 3/8" OD (McMaster-Carr [#9657K289](https://www.mcmaster.com/products/9657k289/))
- 1x 1/4" washer, zinc (optional) (McMaster-Carr [#92141A029](https://www.mcmaster.com/products/92141a029/))
- 1x 1/4"-20 plastic knob with brass threaded insert (McMaster-Carr [#6185K21](https://www.mcmaster.com/6185K21/) or hardware store)

### Hardware Stack

From top to bottom:

```
[ bolt head ]
[ toe clamp insert ]
[ toe clamp body ]
[ nut ]
[ spring ]       ← stiffer is better, helps the toe clamp to "spring" up after loosening
[ connector body (butt or saw horse) ]
[ washer ]       ← optional, add if you can't tighten enough
[ knob ]
```

### Steps

1. **Print** `toe_clamp_body` in TPU and `toe_clamp_insert` in PLA.
2. **Insert** the `toe_clamp_insert` into the pocket of the `toe_clamp_body`. The insert is sized slightly smaller than the body cavity (`TOE_CLAMP_INSERT_WIDTH` and `TOE_CLAMP_INSERT_LENGTH` are each 2mm smaller than the body) so it should fit snugly.
3. **Thread the bolt** down through the center hole, passing through the insert and body.
4. **Thread a nut** onto the bolt below the clamp body.
5. **Add the spring** below the nut.
6. **Drop the assembly** through the channel slot in the connector body (butt or saw horse connector) so the spring sits against the underside of the connector.
7. **Add the optional washer** below the connector body, then **thread on the knob** to complete the assembly.
8. **Tighten the knob** to compress the spring and drive the toe clamp body against the fence rail.

---

## Butt Connector Assembly

The butt connector joins two sections of Best Fence end-to-end. It uses 2 channel slots (one toe clamp per slot) and mounts from the **bottom** of the fence using a "Helping Hand" arm.

### Parts needed
- 1x `butt_connector` (PLA)
- 2x toe clamp assemblies (see above)
- 1x [FastCap 3rd Hand](https://www.fastcap.com/products/3rd-hand-series) arm

### Steps

1. **Print** `butt_connector` in PLA.
2. **Assemble two toe clamps** per the Toe Clamp Assembly instructions above.
3. **Clip the FastCap 3rd Hand** onto the bottom of the Best Fence rail, then **slide the connector** onto the arm so it seats in the cylindrical pocket on the underside.
4. **Position the connector** across the joint between two fence sections — roughly centered, with one channel on each section. Exact centering isn't critical; just make sure each channel is on a different fence section.
5. **Insert a toe clamp assembly** into each channel slot and **tighten the knobs** to lock both sections in place.

---

## Saw Horse Connector Assembly

The saw horse connector mounts a single section of Best Fence onto a saw horse. It uses 1 channel slot (one toe clamp) and mounts from the **top** of the connector down into the saw horse surface using 4 screws.

### Parts needed
- 1x `saw_horse_connector` (PLA)
- 1x toe clamp assembly (see above)
- 4x #10 wood screws
- 1x wood mounting block (user-provided)

### Steps

1. **Print** `saw_horse_connector` in PLA.
2. **Assemble one toe clamp** per the Toe Clamp Assembly instructions above.
3. **Mount a wood block** to the saw horse at the desired fence position. The block lets you tune the exact height of the fence rail — size and attach it however works for your saw horse.
4. **Screw the connector** to the wood block using 4x #10 wood screws through the 2×2 hole pattern (32mm spacing).
5. **Slide the fence rail** into the connector channel.
6. **Insert the toe clamp assembly** and **tighten the knob** to lock the fence in place.

---

## Adjusting Dimensions

All geometry is driven by variables in `config.scad`. If your printed parts are too tight or too loose:

- `TOE_CLAMP_TOLERANCE_LENGTH` — adjusts fit along the length of the channel (default: +1mm)
- `TOE_CLAMP_TOLERANCE_WIDTH` — adjusts fit across the width of the channel (default: -3mm)
- `MOUNT_VERTICAL_CLEARANCE` — controls how far the mount sits above/below the top of the fence rail (default: -2mm, meaning 2mm below the top edge)

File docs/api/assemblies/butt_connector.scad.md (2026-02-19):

# File: butt\_connector.scad

This file defines the assembly for the butt connector, which includes the toe clamp body, toe clamp insert, and bolts.
It uses the parts defined in parts/butt_connector.scad.

To use, add the following lines to the beginning of your file:

    include <assemblies/butt_connector.scad>;

## File Contents

- [`butt_connector_assembly`](#module-butt_connector_assembly)

### Module: butt\_connector\_assembly

**Usage:** 

- butt_connector_assembly();

**Description:** 

This module assembles the butt connector by combining the toe clamp body, toe clamp insert, and bolts in the correct orientation and position.

**Example 1:** 

``` {.C linenos=True}
include <assemblies/butt_connector.scad>;
butt_connector_assembly();
```

butt\_connector\_assembly Example 1

---

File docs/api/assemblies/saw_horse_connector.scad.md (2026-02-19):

# File: saw\_horse\_connector.scad

This file defines the assembly for the saw horse connector, which includes the toe clamp body, toe clamp insert, and bolts.
It uses the parts defined in parts/saw_horse_connector.scad.

To use, add the following lines to the beginning of your file:

    include <assemblies/saw_horse_connector.scad>;

## File Contents

- [`saw_horse_connector_assembly`](#module-saw_horse_connector_assembly)

### Module: saw\_horse\_connector\_assembly

**Usage:** 

- saw_horse_connector_assembly();

**Description:** 

This module assembles the saw horse connector by combining the toe clamp body, toe clamp insert, and bolts in the correct orientation and position.

**Example 1:** 

``` {.C linenos=True}
include <assemblies/saw_horse_connector.scad>;
saw_horse_connector_assembly();
```

saw\_horse\_connector\_assembly Example 1

---

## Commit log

2026-02-18 Refactor documentation and model files for Best Fence system
    - Updated documentation for toe clamp components to remove unnecessary references to mount.
    - Revised assembly instructions and BOM to include placeholders for future updates.
    - Added new libraries for attachment mechanisms (attachment_helping_hand, attachment_screw, bolt).
    - Created new models for butt and saw horse connectors, integrating existing components.
    - Improved mount module to validate arguments and calculate support/channel points.
    - Adjusted preview files to utilize new connector models and streamline rendering.
    - Fixed paths in scripts to align with updated directory structure.
    [butt_connector.scad, saw_horse_connector.scad, toe_clamp_body.scad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]
2026-02-19 Clean up .gitignore and remove unused source hashes
    [saw_horse_connector.scad]
2026-02-19 Add new assembly and tool components for Best Fence system
    [attachment_helping_hand.scad, attachment_screw.scad, bolt.scad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]
2026-02-19 Enhance assembly modules and documentation for butt and saw horse connectors; add screw module and update scripts
    [attachment_screw.scad, butt_connector.scad, saw_horse_connector.scad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]
2026-02-19 added spring + bolt channels
    [config.scad, mount.scad]
2026-02-19 applying best practices
    [attachment_helping_hand.scad, attachment_screw.scad, bolt.scad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]
2026-02-19 updated files to follow standards, ran `make docs`
    [attachment_helping_hand.scad, attachment_screw.scad, bolt.scad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]
